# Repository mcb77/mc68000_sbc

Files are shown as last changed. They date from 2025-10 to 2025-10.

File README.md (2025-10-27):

# MC68000 Single Board Computer

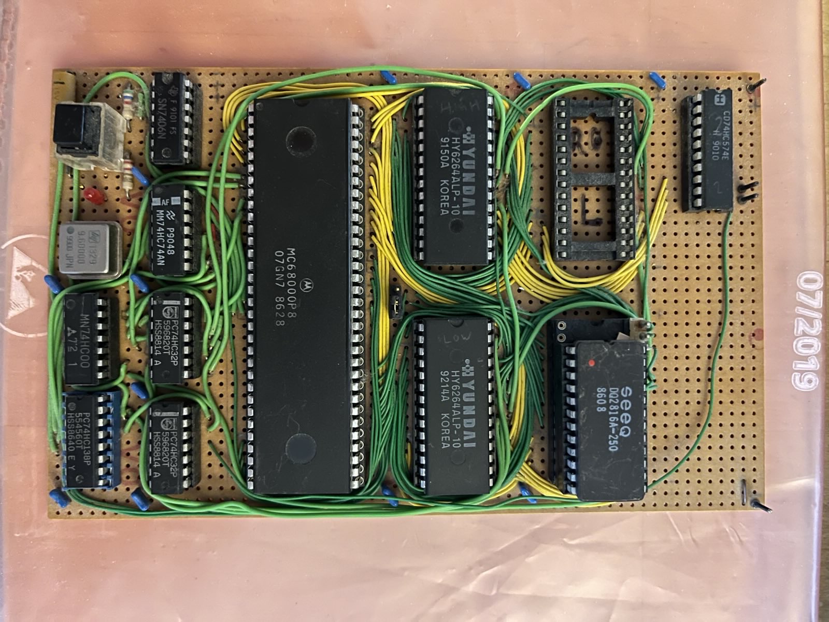
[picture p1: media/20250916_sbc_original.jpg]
original


## Updates
### 2025-09-16 
- Searched for the circuit board in old moving boxes and found it. 
- Reverse engineering of the circuit diagram and drawing in Kicad.

#### Reverse engineering facts
- MC68000 CPU running at 4.8MHz
- 1MB mapped from 0x000000 to 0x0fffff for RAM. (2x8kb 6264 static RAM)
- 1MB mapped from 0x100000 to 0x1fffff for ROM. (2x2kb 2816 EEPROM. Only the high byte EEPROM is still installed.)
- 1MB mapped from 0x200000 to 0x2fffff for IO. (One 74HC574 Latch for 8-bit output)
- During reset the ROM is remapped to 0x000000 so that the initial SP and PC can be loaded from ROM. Any read operation which triggers A23 to high disables the remapping of the ROM and the normal memory map is activated until the next reset.

### 2025-09-18
- Searched for second 2816 in old moving boxes. Found one in an other old sbc project. Since this is not the missing low byte EEPROM, there is no chance to test the 68000 without writing new code first.

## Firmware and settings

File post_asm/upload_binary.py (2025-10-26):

import serial
import sys
import time

def open_serial_port(port, baud=9600, timeout=0.1):
    """Open serial port with specified settings."""
    try:
        ser = serial.Serial(
            port=port,
            baudrate=baud,
            bytesize=serial.EIGHTBITS,
            parity=serial.PARITY_NONE,
            stopbits=serial.STOPBITS_ONE,
            timeout=timeout
        )
        print(f"Opened serial port {port}")
        return ser
    except serial.SerialException as e:
        print(f"Error opening serial port {port}: {e}")
        sys.exit(1)

def read_binary_file(filename):
    """Read binary file into bytes."""
    try:
        with open(filename, 'rb') as f:
            data = f.read()
        print(f"Read {len(data)} bytes from {filename}")
        return data
    except FileNotFoundError:
        print(f"Error: File {filename} not found")
        sys.exit(1)
    except Exception as e:
        print(f"Error reading file {filename}: {e}")
        sys.exit(1)

def read_line(ser, timeout=1):
    """Read a line until newline or timeout."""
    start_time = time.time()
    line = b""
    while time.time() - start_time < timeout:
        char = ser.read(1)
        if not char:  # Timeout on read
            continue
        line += char
        if char == b'\n':
            try:
                return line.decode('ascii', errors='ignore').strip('\r\n')
            except UnicodeDecodeError:
                return ""
        time.sleep(0.001)  # Small delay to avoid CPU hogging
    return ""  # Timeout, return empty string

def send_command(ser, command, timeout=0.1):
    """Send command with LF terminator and read response line."""
    ser.write((command + '\n').encode('ascii'))
    time.sleep(0.01)  # Wait for SBC response
    response = read_line(ser, timeout)
    return response

def upload_binary(ser, filename, start_addr,execute):
    """Upload binary file to SBC and jump to start address."""
    data = read_binary_file(filename)

    # Send write commands
    addr = start_addr
    for byte in data:
        command = f"write {addr:06X},{byte:02X}"
        print(f"Sending: {command}")
        response = send_command(ser, command)
        print(f"Response: {response}")
        if "Error" in response:
            print(f"Error from SBC: {response}")
            return False
        addr += 1

    print("Upload successful")

    if execute == 1:
        # Send jump command
        command = f"jump {start_addr:06X}"
        print(f"Sending: {command}")
        response = send_command(ser, command)
        print(f"Response: {response}")
        if "Error" in response:
            print(f"Error from SBC: {response}")
            return False

    print("Execute successful")
    return True

def main():
    if len(sys.argv) != 5:
        print("Usage: python upload_binary.py <port> <filename> <start_addr> <execute_flag>")
        print("Example: python upload_binary.py /dev/ttyUSB0 program.bin 003000 1")
        sys.exit(1)

    port = sys.argv[1]
    filename = sys.argv[2]
    try:
        start_addr = int(sys.argv[3], 16)
    except ValueError:
        print("Error: Start address must be a hexadecimal number")
        sys.exit(1)

    try:
        execute = int(sys.argv[4])
    except ValueError:
        print("Error: Execute flag must be a 0 or 1")
        sys.exit(1)


    # Open serial port
    ser = open_serial_port(port)

    try:
        # Flush input buffer
        ser.reset_input_buffer()

        # Upload binary
        if upload_binary(ser, filename, start_addr, execute):
            print("Program uploaded and executed")
            # Read any output (e.g., program output)
            time.sleep(1)
            response = read_line(ser, timeout=2)
            while response:
                print("SBC output:", response)
                response = read_line(ser, timeout=2)
        else:
            print("Upload failed")

    finally:
        ser.close()
        print("Serial port closed")

if __name__ == "__main__":
    main()

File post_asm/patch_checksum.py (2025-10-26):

#!/usr/bin/env python3
import sys

# Constants
EPROM_SIZE = 16384  # Total size of ROM (bytes, for two 2764 EPROMs)
CHECKSUM_SIZE = 4   # Size of checksum (bytes)

# Read input binary
with open(sys.argv[1], 'rb') as f:
    data = f.read()

# Pad to EPROM_SIZE bytes with 0xFF
pad_length = EPROM_SIZE - len(data)
data += b'\xFF' * pad_length

# Compute sum of first EPROM_SIZE - CHECKSUM_SIZE bytes (modulo 2^32)
sum_bytes = sum(data[i] for i in range(EPROM_SIZE - CHECKSUM_SIZE)) & 0xffffffff

# Store sum as big-endian 32-bit checksum in last 4 bytes
data = data[:EPROM_SIZE - CHECKSUM_SIZE] + bytes([
    (sum_bytes >> 24) & 0xff,  # b0: MSB
    (sum_bytes >> 16) & 0xff,  # b1
    (sum_bytes >> 8) & 0xff,   # b2
    sum_bytes & 0xff           # b3: LSB
])

# Write back to input file
with open(sys.argv[1], 'wb') as f:
    f.write(data)

print(f"Patched 32-bit checksum 0x{sum_bytes:08x} into {sys.argv[1]} at 0x{EPROM_SIZE - CHECKSUM_SIZE:06x}")

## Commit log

2025-10-26 Add kicad schematics
    [mc68000_sbc.kicad_pcb, mc68000_sbc.kicad_sch]
2025-10-26 Add simple program to flash the LED.
2025-10-26 Add serial bridge for Arduino uno.
2025-10-26 Add variant of LED flash program which can be uploaded via the monitor into RAM.
